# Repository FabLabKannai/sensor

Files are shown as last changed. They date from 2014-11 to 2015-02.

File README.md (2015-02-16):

FabLab Kannai Sensor Project
======

### Arduino Sensor Shield.
This shield have sensors below .<br>
- Temperature and humidity : DHT11<br>
- Air Pressure : MPL115A2<br>
- Light : NJL7502L<br>
- Noise : Condenser Microphone C9267<br>

Separately, requires the Arduino UNO and WiFi shield .<br>

## Sample code
Two types of Arduino sketch 
- Display the measured values on the PC with USB serial.
- Send the measured values to the server with WiFi shield.

Server side program
- Receive the measured values, and display on WEB site.

## Directries
arduino : Arduino sketch <br>
server : Server side program, PHP <br>
eagle : Board data, Eagle format <br>
case : Case data, Adobe illustrator format <br>
docs : Photos and documents <br>

## License
Souce code : Apache License 2.0<br>
Othes :  Creative Commons BY-SA

## Blog (in Japanese)
Sensor Project<br>
http://fablab-kannai.org/sensor_project <br>
Arduino Sensor Shield<br>
http://fablab-kannai.org/archives/787 <br>

## Photo
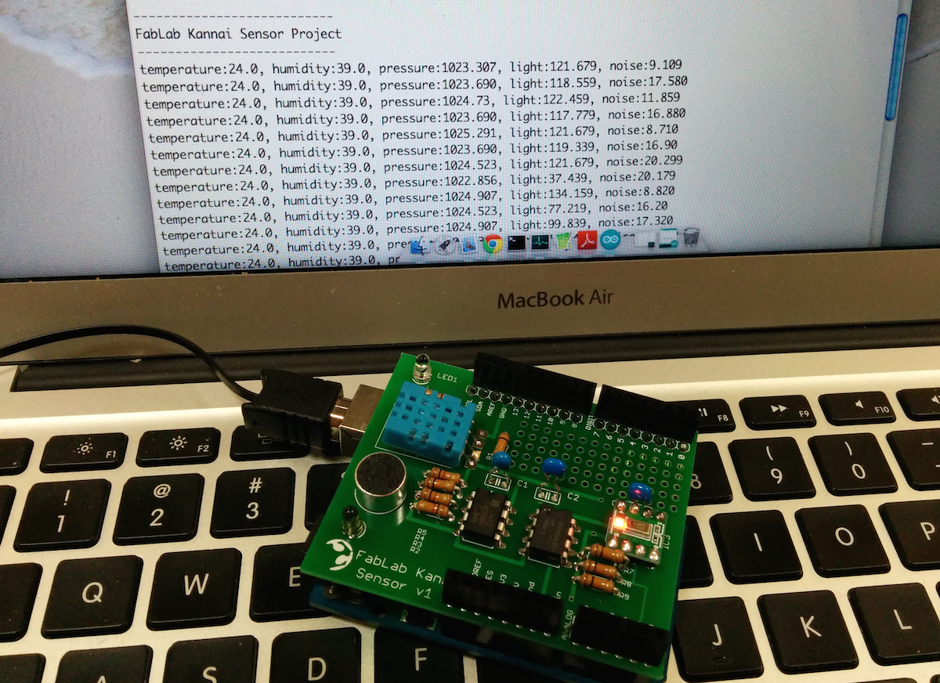
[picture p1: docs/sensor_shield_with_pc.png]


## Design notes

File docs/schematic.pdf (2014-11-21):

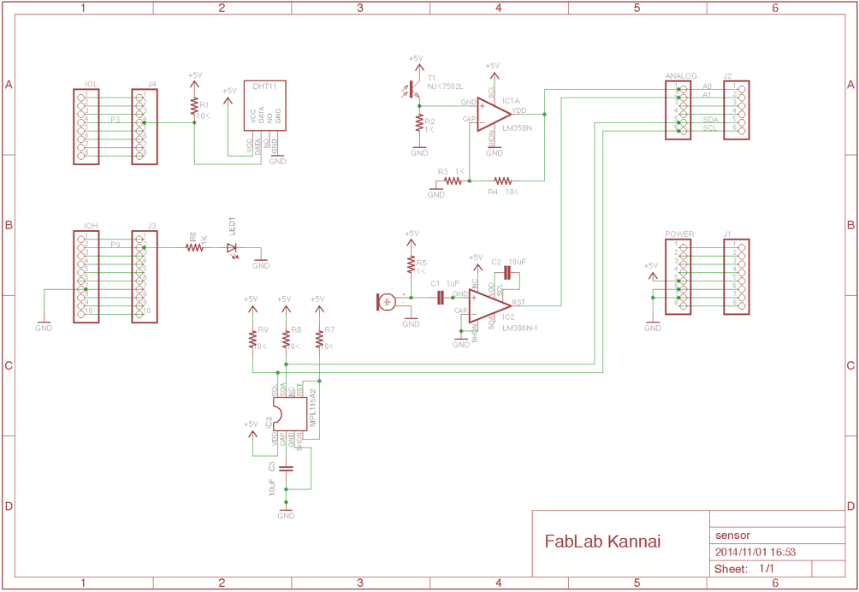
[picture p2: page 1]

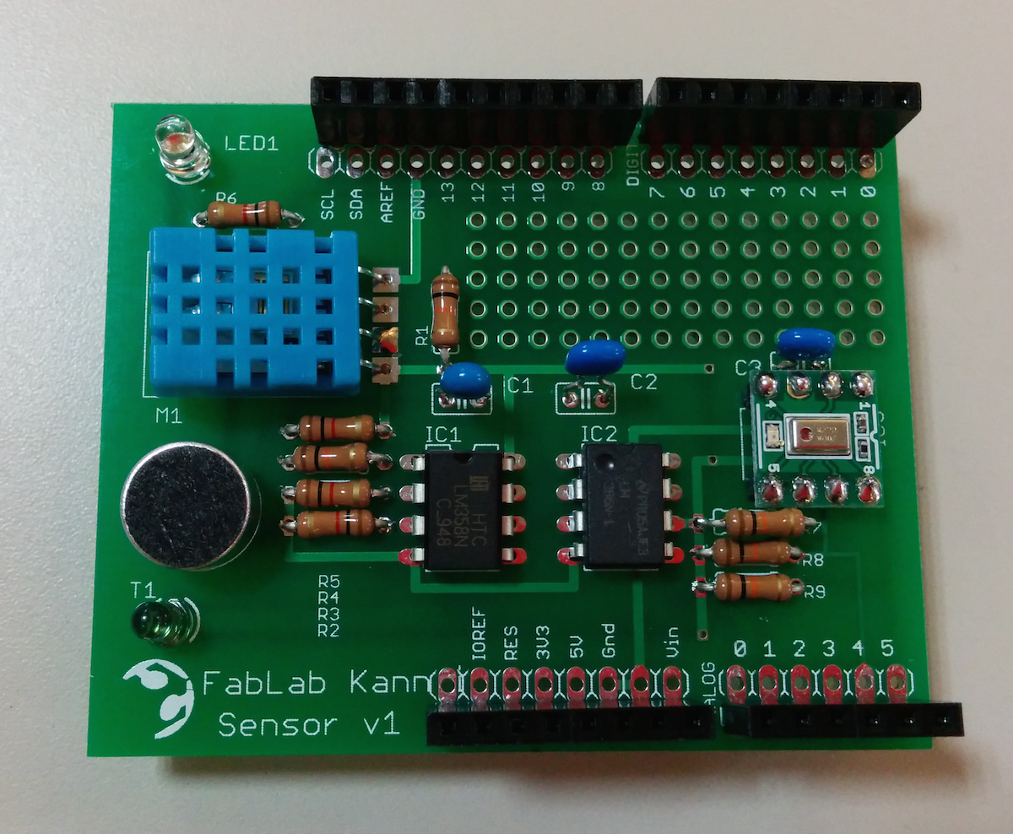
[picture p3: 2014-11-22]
docs/board_front.png

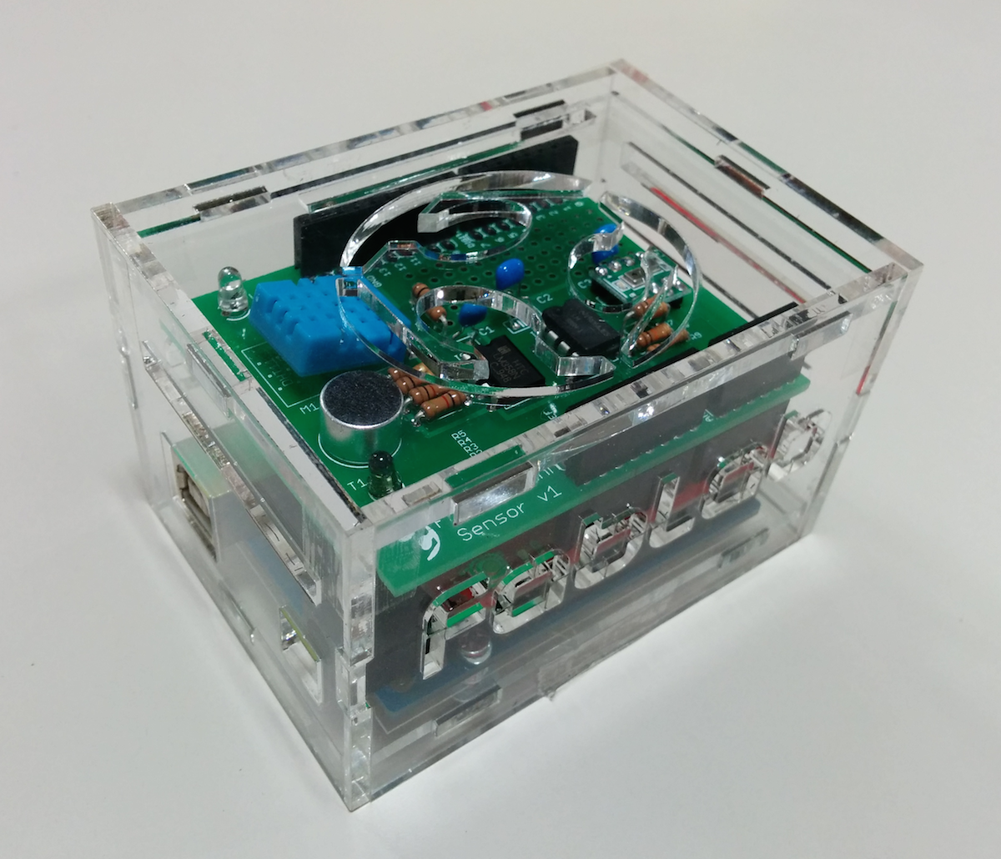
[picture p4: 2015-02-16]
docs/sensor_case.png

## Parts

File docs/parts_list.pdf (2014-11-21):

### Fab-Sensor 部品リスト

種類 | シンボル名 | 品名 | 購入先
基板 | --- | --- | ---
オペアンプ | IC1 | LM358N | http://akizukidenshi.com/catalog/g/gI-02324/
オーディオアンプ | IC2 | LM386N-1 | http://akizukidenshi.com/catalog/g/gI-02250/
気圧センサ | IC3 | MPL115A2 | http://akizukidenshi.com/catalog/g/gI-06521/
温度・湿度センサ | U1 | DHT11 | http://akizukidenshi.com/catalog/g/gM-07003/
光センサ | T1 | NJL7502L | http://akizukidenshi.com/catalog/g/gI-02325/
マイク | M1 | C9267 | http://akizukidenshi.com/catalog/g/gP-01810/
LED | LED1 | LED3MM | http://akizukidenshi.com/catalog/g/gI-00562/
抵抗 | R1,R4,R7,R8,R9 | 10KΩ | http://akizukidenshi.com/catalog/g/gR-25103/
| R2,R3,R5,R6 | 1KΩ | http://akizukidenshi.com/catalog/g/gR-25102/
コンデンサー | C1 | 1uF | http://akizukidenshi.com/catalog/g/gP-03093/
| C2,C3 | 10uF | http://akizukidenshi.com/catalog/g/gP-03095/
ピンヘッダー | IOH | 1x10 | http://akizukidenshi.com/catalog/g/gC-07199/
| POWER, IOH | 1x8 | http://akizukidenshi.com/catalog/g/gC-04046/
| ANALOG | 1X6 | http://akizukidenshi.com/catalog/g/gC-04045/

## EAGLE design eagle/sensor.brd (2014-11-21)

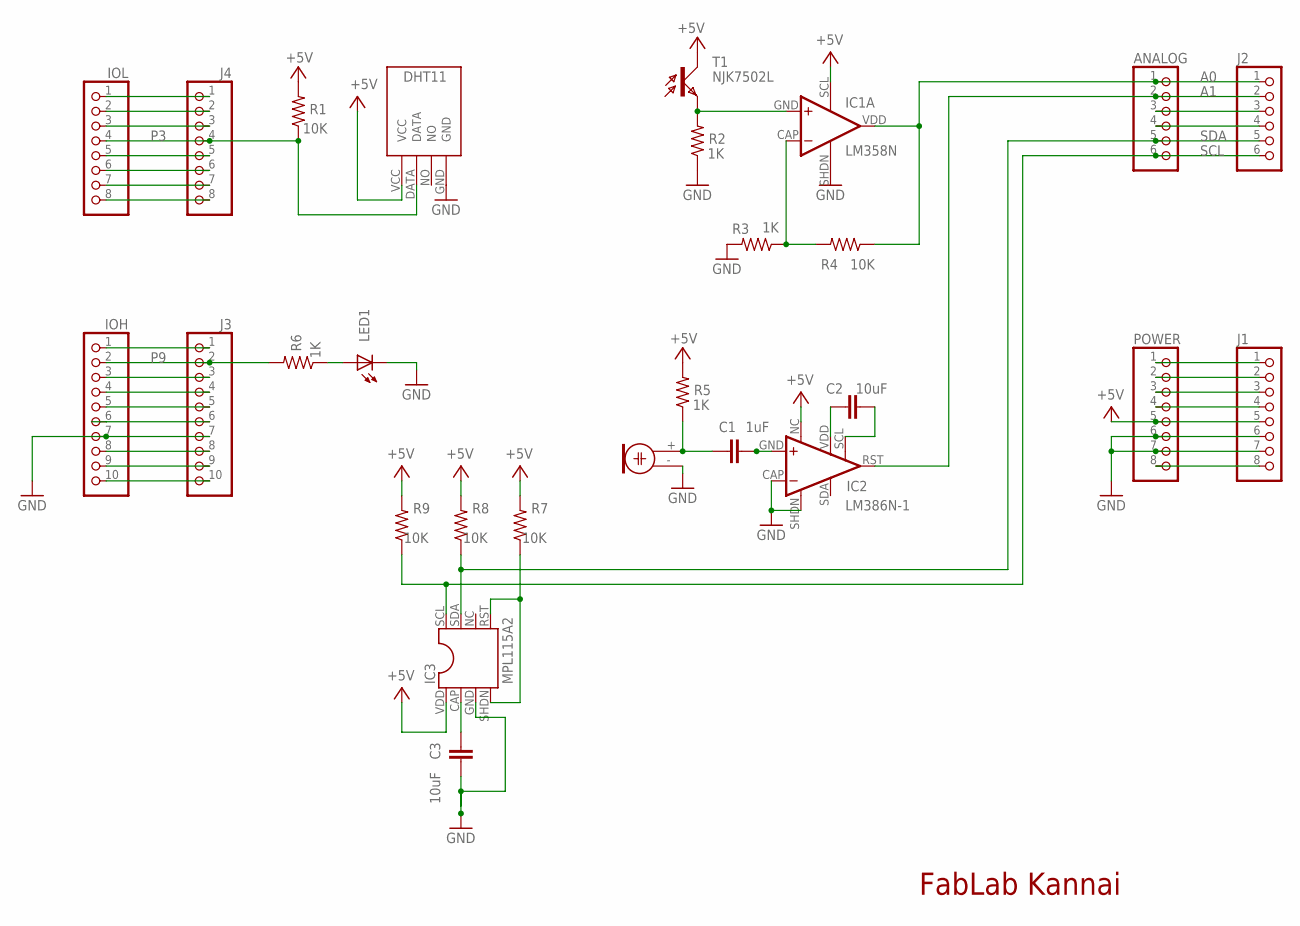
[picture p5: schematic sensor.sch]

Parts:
ANALOG: PINHD-1X6; 1X06
C1: 1uF; C025-025X050
C2, C3: 10uF; C025-025X050
IC1: LM358N; MPL115A2-DIL08
IC2: LM386N-1; MPL115A2-DIL08
IC3: MPL115A2; MPL115A2-DIL08
IOH: PINHD-1X10TH; 1X10-TH
IOL: PINHD-1X8TH; 1X08-TH
J1, J4: PINHD-1X8TH; 1X08-TH
J2: PINHD-1X6; 1X06
J3: PINHD-1X10TH; 1X10-TH
LED1: LED3MM
M1: C9257; DB-C9767
POWER: PINHD-1X8TH; 1X08-TH
R1, R4, R7, R8, R9: 10K; 0204/7
R2, R3, R5, R6: 1K; 0204/7
T1: NJK7502L; NJL7502L
U$1: DHT11

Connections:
+9V: J1.8, POWER.8
A0: ANALOG.1, IC1.VDD (OUT), J2.1, R4.1
A1: ANALOG.2, IC2.RST (OUT), J2.2
A2: ANALOG.3, J2.3
A3: ANALOG.4, J2.4
AREF: IOH.8, J3.8
GND: C3.2, IC1.SHDN (V-), IC2.CAP (-IN), IC2.SHDN (GND), IC3.GND, IOH.7, J1.6, J1.7, J3.7, LED1.K (C), M1.- (2), POWER.6, POWER.7, R2.1, R3.2, U$1.GND
unnamed: IOH.9, J3.9
unnamed: IOH.10, J3.10
unnamed: IC1.SCL (V+), IC2.NC (VS), IC3.VDD, J1.5, POWER.5, R1.2, R5.2, R7.2, R8.2, R9.2, T1.C, U$1.VCC
unnamed: IC1.GND (+IN), R2.2, T1.E
unnamed: IC3.RST, IC3.SHDN, R7.1
unnamed: IC1.CAP (-IN), R3.1, R4.2
unnamed: C3.1, IC3.CAP
unnamed: C2.1, IC2.VDD (GAIN)
unnamed: J1.2, POWER.2
unnamed: J1.1, POWER.1
unnamed: C1.2, IC2.GND (+IN)
unnamed: C2.2, IC2.SCL (GAIN)
unnamed: C1.1, M1.+ (1), R5.1
unnamed: LED1.A, R6.1
unnamed: J1.4, POWER.4
P0: IOL.1, J4.1
P1: IOL.2, J4.2
P2: IOL.3, J4.3
P3: IOL.4, J4.4, R1.1, U$1.DATA
P4: IOL.5, J4.5
P5: IOL.6, J4.6
P6: IOL.7, J4.7
P7: IOL.8, J4.8
P8: IOH.1, J3.1
P9: IOH.2, J3.2, R6.2
P10: IOH.3, J3.3
P11: IOH.4, J3.4
P12: IOH.5, J3.5
P13: IOH.6, J3.6
RESET: J1.3, POWER.3
SCL: ANALOG.6, IC3.SCL, J2.6, R9.1
SDA: ANALOG.5, IC3.SDA, J2.5, R8.1

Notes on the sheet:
FabLab Kannai

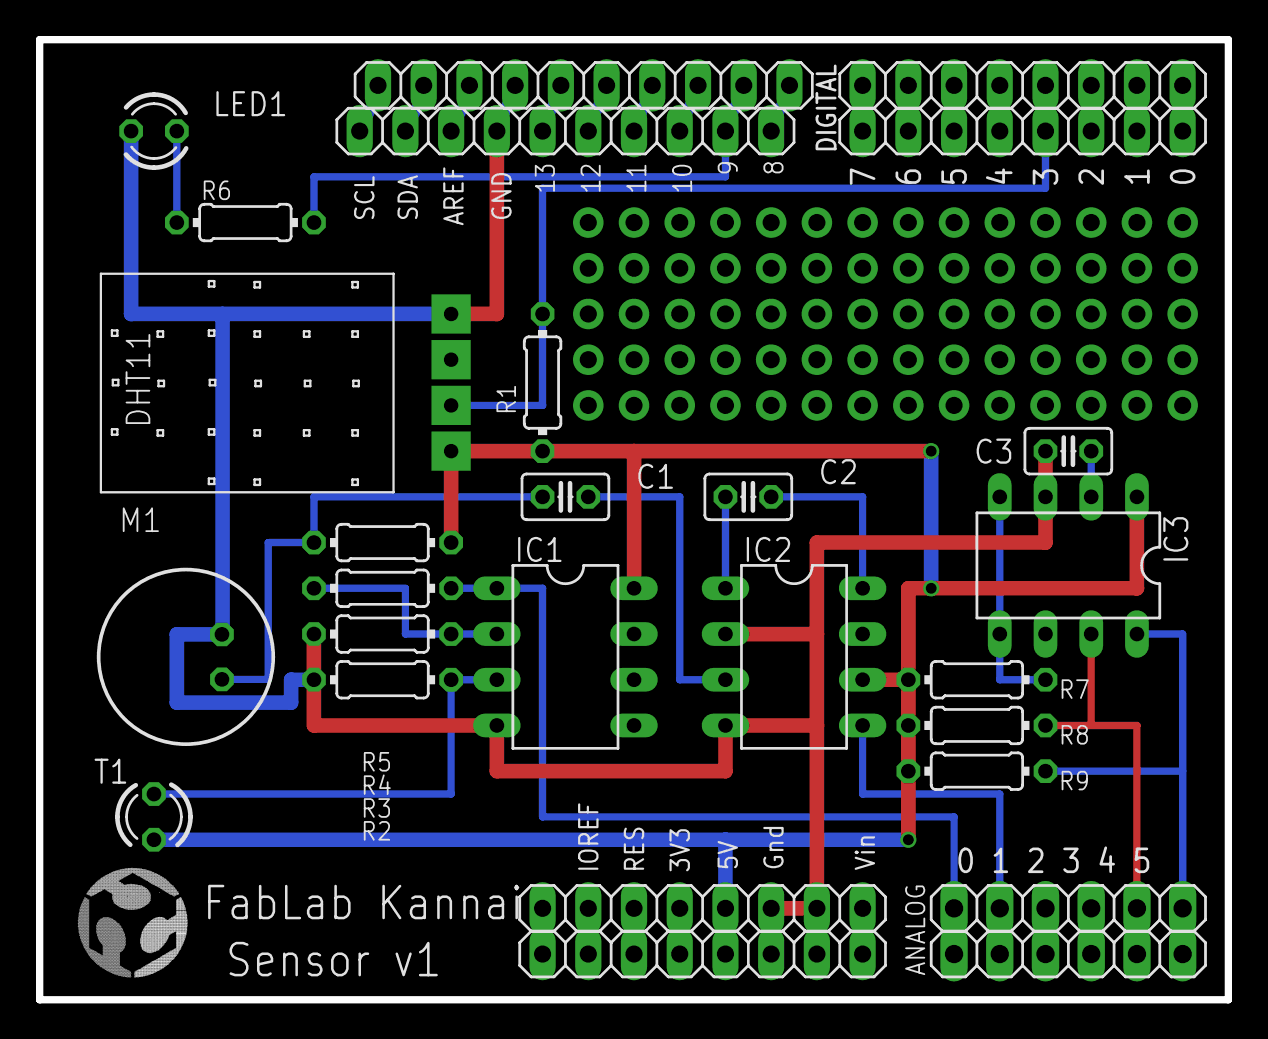
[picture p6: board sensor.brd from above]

Board: 2 copper layers, 66.0 x 53.3 mm, 27 parts (0 on the bottom side), 39 nets.

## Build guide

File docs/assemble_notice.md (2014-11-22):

ハンダ付けする際の注意
==========================

(1) LEDと光センサは、外観の形状は同じなので、色で識別してください。LEDは無色 (発光色は青) で、光センサは深緑色です。基板のシルクからは極性が判断できません。下図を参考にしてください。<br>
(2) 気圧センサと抵抗の間に物理的な余裕がありません。抵抗をハンダ付けしたあとで、気圧センサをハンダ付けしてください。<br>
(3) コンデンサのピンの幅は２ピッチですが、基板は１ピッチです。ピンを伸ばすなどして、取り付けてください。<br>

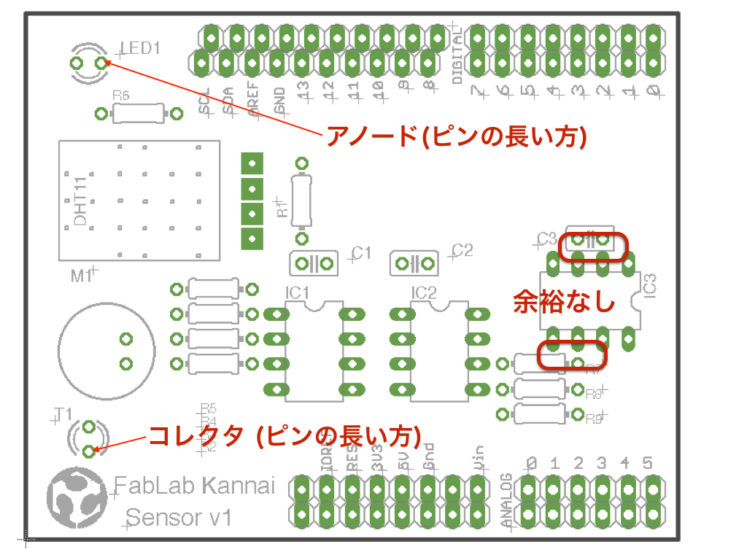
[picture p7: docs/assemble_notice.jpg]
notice


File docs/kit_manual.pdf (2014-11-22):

# FabLab Kannai センサー・シールド

# Arduino 用のシールドです。

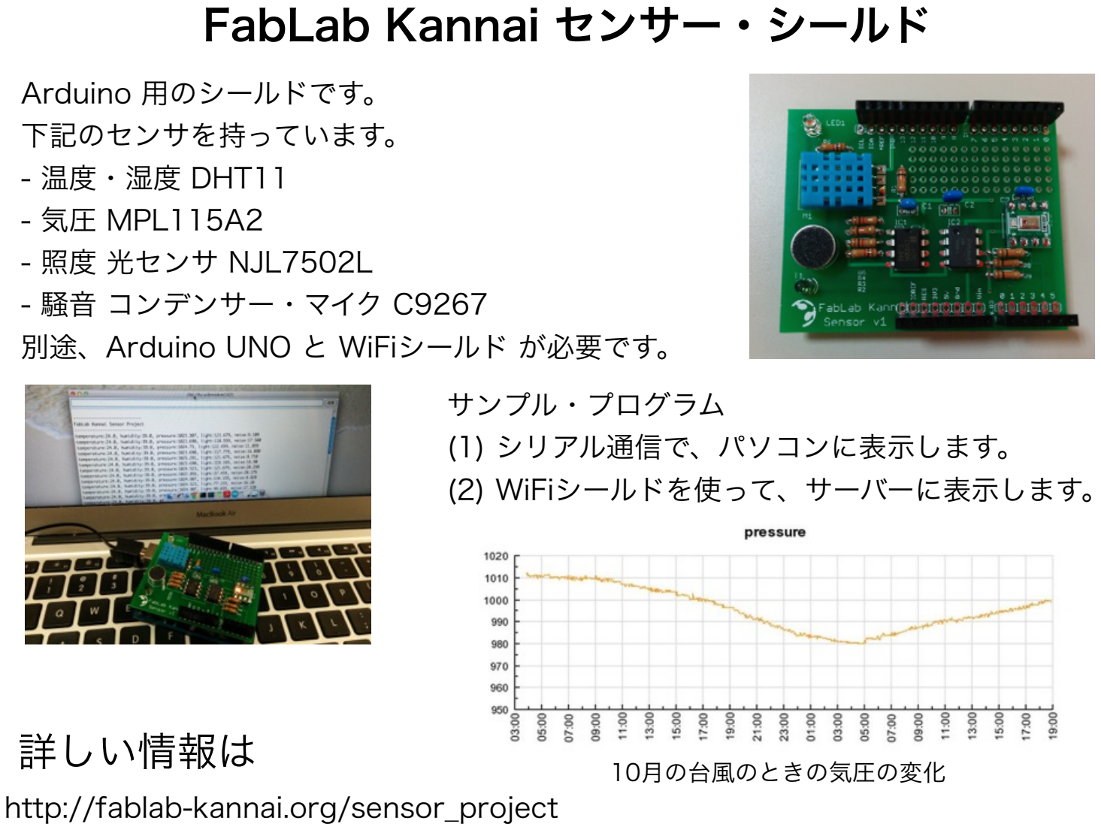
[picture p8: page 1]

# 下記のセンサを持っています。 - 温度・湿度 DHT11 - 気圧 MPL115A2 - 照度 光センサ NJL7502L - 騒音 コンデンサー・マイク C9267 別途、Arduino UNO と WiFiシールド が必要です。

# サンプル・プログラム (1) シリアル通信で、パソコンに表示します。 (2) WiFiシールドを使って、サーバーに表示します。

# 10月の台風のときの気圧の変化

# http://fablab-kannai.org/sensor_project

# 詳しい情報は

# FabLab Kannai センサー・シールド

種類 | シンボル名 | 品名
基板 | --- | ---
オペアンプ | IC1 | LM358N
オーディオアンプ | IC2 | LM386N-1
気圧センサ | IC3 | MPL115A2
温度・湿度センサ | U1 | DHT11
照度センサ | T1 | NJL7502L
マイク | M1 | C9267
LED | LED1 | LED3MM
抵抗 | R1,R4,R7,R8,R9 | 10KΩ

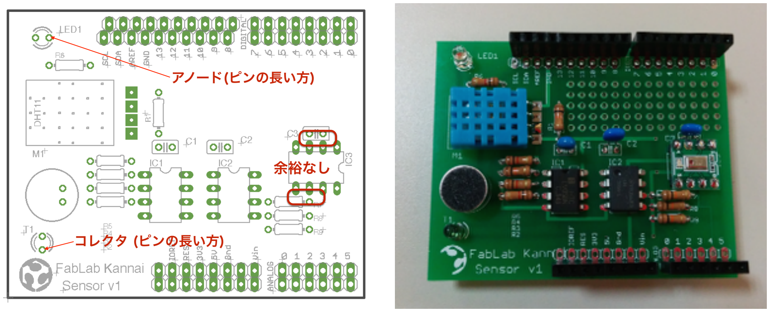
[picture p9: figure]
アノード(ピンの長い方); コレクタ (ピンの長い方); 余裕なし

R2,R3,R5,R6 | 1KΩ
コンデンサー | C1 | 1uF
| C2,C3 | 10uF
ピンヘッダー | IOH | 1x10
| POWER, IOH | 1x8
| ANALOG | 1X6

# (1) LEDと光センサは、外観の形状は同じなので、色で識別 してください。LEDは無色 (発光色は青) で、光センサは深 緑色です。 基板のシルクからは極性が判断できません。下 図を参考にしてください。 (2) 気圧センサと抵抗の間に物理的な余裕がありません。 抵抗をハンダ付けしたあとで、気圧センサをハンダ付けして ください。 (3) コンデンサのピンの幅は２ピッチですが、基板は１ピッ チです。ピンを伸ばすなどして、取り付けてください。

部品リスト | ハンダ付けする際の注意

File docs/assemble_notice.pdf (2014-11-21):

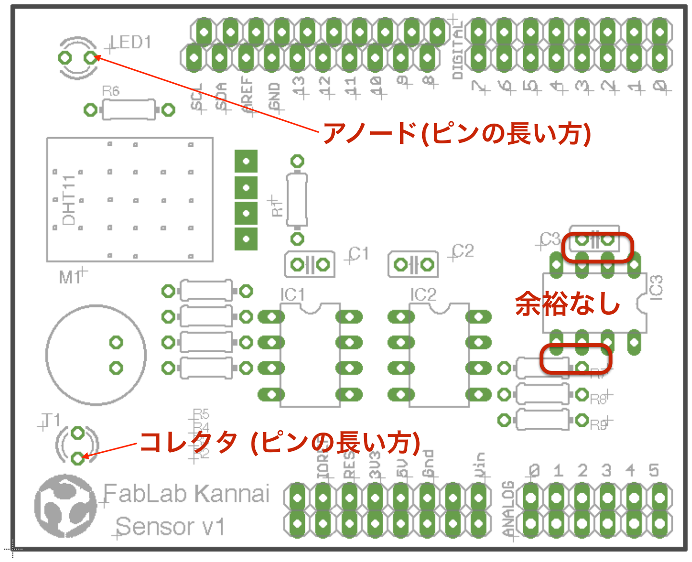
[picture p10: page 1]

アノード(ピンの長い方)

コレクタ (ピンの長い方)

余裕なし

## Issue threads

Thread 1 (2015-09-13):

Light Sensor Coefficient

stelgenhof, 2015-09-13:
Hi,

Thank you very much for this sensor project. I am building this myself and am wondering what the coefficient number in the sensor code (0.78) is representing.

It looks like it is used for converting the analogue pin out to a Lux value. Is that correct. I am using the same light photo diode (NJ7502) and was wondering how you determined that number 0.78. I have made a formula for converting to Lux, but am not convinced the output is correct.

Closed 2023-12-04.

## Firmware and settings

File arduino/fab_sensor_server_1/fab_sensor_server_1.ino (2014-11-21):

/**
 * Sensor for Server with Wifi
 * Temperature, Humidity, Light, Noise,  Air Pressure
 * 
 * FabLab Kannai Sensor Project
 * 2014-08-20
 */ 

/*
 * require
 * SFE_CC3000_Library 
 *   https://github.com/sparkfun/SFE_CC3000_Library
 *   and modify SFE_CC3000.cpp
 * Arduino Library for the DHT11
 *   https://github.com/adafruit/DHT-sensor-library
 * Driver for the Adafruit MPL115A2 barometric pressure sensor breakout
 *   https://github.com/adafruit/Adafruit_MPL115A2
 */

/**
 * send data
 * { "temperature":11.1, "humidity":22.2, "light":33.3, "noise":44.4, "pressure":55.5 }
 *
 * response
 * { "code": 1 }
 */

/**
 * Sensor Device
 * Temperature & Humidity : DHT11
 * Air Pressure : MPL115A2
 * Light : NJL7502L
 * Noise : Microphone C9767BB422LFP
 */

// WiFi 
#include <SPI.h>
#include <SFE_CC3000.h>
#include <SFE_CC3000_Client.h>

// Air Pressure
#include <Wire.h>
#include <Adafruit_MPL115A2.h>

// Temperature & Humidity
#include <DHT.h>

#include <avr/wdt.h>
#include "config.h"

// Pins
#define CC3000_INT  2  // Needs to be an interrupt pin (D2/D3)
#define CC3000_EN  7  // Can be any digital pin
#define CC3000_CS  10  // Preferred is pin 10 on Uno
#define PIN_DHT  3
#define PIN_LED  9
#define PIN_LIGHT  A0
#define PIN_NOISE  A1

// param
#define PARAM_TEMP   "param={\"temperature\":"
#define PARAM_HUMI   ",\"humidity\":"
#define PARAM_LIGHT  ",\"light\":"
#define PARAM_NOISE  ",\"noise\":"
#define PARAM_PRESS  ",\"pressure\":"
#define PARAM_END    "}"

// Sensor   
#define DHTTYPE  DHT11   // DHT 11 
#define UNDIFINED_VALUE  -1
#define NOISE_OFFSET 512
#define AVARAGE_NUM  100
#define DECIMAL_DIGIT  1000

// --- todo ---
#define COFF_LIGHT  0.78

// Serial
#define SERIAL_SPEED  9600

// Access Point
#define IP_ADDR_LEN  4  // Length of IP address in bytes
#define AP_TIMEOUT  30000  // 30 sec
#define AP_SECURITY  WLAN_SEC_WPA2  // Security of network

// Server
#define SERVER_PORT  80
#define SERVER_PATH_BEGIN  "/~"

// Response
#define TIME_RESPONSE  1  // 1 msec
#define RESPONSE_TIMEOUT  5000  // 5 sec

// loop
#define MAX_NOT_SEND  10
#define TIME_LOOP  1000  // 1 sec

// CC3000
SFE_CC3000 wifi = SFE_CC3000( CC3000_INT, CC3000_EN, CC3000_CS );
SFE_CC3000_Client client = SFE_CC3000_Client( wifi );

// DHT
DHT dht( PIN_DHT, DHTTYPE );

// MPL115A2
Adafruit_MPL115A2 mpl115a2;

// Server IP Address
IPAddress host_addr;

// length of param characters
int param_len = 0;

// led
boolean led_status = false;

// counter that cannot send wifi 
unsigned int cnt_not_send = 0;

// time which excute to send data
unsigned long time_excute = 0;

boolean is_connected = false;

// proc wdt_reset if 1
boolean is_wdt = true;

/**
 * === setup ===
 */ 
void setup() {
	// Initialize Serial port
	Serial.begin( SERIAL_SPEED );
	Serial.println();
	Serial.println( F("---------------------------") );
	Serial.println( F("FabLab Kannai Sensor Project") );
	Serial.println( F("---------------------------") );
	// setting
	pinMode( PIN_LED, OUTPUT );	
	dht.begin();
	mpl115a2.begin();	
	setup_wifi();
	setup_param_len();
	wdt_enable( WDTO_8S );
}

/**
 * setup_wifi
 */
void setup_wifi() {  
	// Initialize CC3000 (configure SPI communications)
	if ( wifi.init() ) {
		Serial.println( F("CC3000 initialization complete") );
	} else {
		Serial.println( F("Something went wrong during CC3000 init!") );
	} 
}

/**
 * setup_param_len
 */
void setup_param_len() {  
	param_len = 0;
	String str = PARAM_TEMP;
	param_len += str.length();
	str = PARAM_HUMI ; 
	param_len += str.length();
	str =  PARAM_LIGHT ;  
	param_len += str.length();
	str = PARAM_NOISE ;
	param_len += str.length();
	str = PARAM_PRESS ;
	param_len += str.length();
	str = PARAM_END ;
	param_len += str.length();
}
	
/**
 * === loop ===
 */ 
void loop() {
	// every 60 sec
	if ( (millis() - time_excute) > TIME_UPLOAD ) {
		time_excute = millis();
		exec_wifi();
	}
	// if wdt enabled
	if ( is_wdt ) {
		wdt_reset();
		// blink LED
		led_status = !led_status;
		if ( led_status ) {
			digitalWrite( PIN_LED, HIGH );
		} else {
  			digitalWrite( PIN_LED, LOW );
		}
	}
	// wait 1 sec
	delay( TIME_LOOP ); 
}

/**
 * exec_wifi
 */
void exec_wifi() {
	is_wdt = true;
	boolean is_ok = false;
	if ( is_connected && wifi.getConnectionStatus() ) {
		if ( send_recv_wifi() ) {
			is_ok = true;
			cnt_not_send = 0;
		}
	} else {
		is_connected = connect_wifi(); 
	}
	if ( !is_ok ) {
		cnt_not_send ++;
	}
	if ( cnt_not_send  > MAX_NOT_SEND ) {
		is_wdt = false;
	}
}

/**
 * connect_wifi
 */
boolean connect_wifi() {
	ConnectionInfo connection_info;
	int i;

	// Connect using DHCP
	Serial.println();
	Serial.print( F("Connecting to SSID: ") );
	Serial.println( F(AP_SSID) );
	if( !wifi.connect( AP_SSID, AP_SECURITY, AP_PASS, AP_TIMEOUT )) {
		Serial.print( F("Error: Could not connect to AP : ") );
		Serial.println( cnt_not_send );
		return false;
	}

	// Gather connection details and print IP address
	if ( !wifi.getConnectionInfo( connection_info ) ) {
		Serial.println( F("Error: Could not obtain connection details") );
		return false;
	}	
	
	Serial.print( F("AP IP Address: ") );
	for (i = 0; i < IP_ADDR_LEN; i++) {
		Serial.print( connection_info.ip_address[ i ] );
		if ( i < IP_ADDR_LEN - 1 ) {
			Serial.print( F(".") );
		}
	}
	Serial.println();

	/* Perform a DNS lookup of the site */
    if ( !wifi.dnsLookup( SERVER_HOST, &host_addr )) {
		Serial.println( F("Error: Could not DNS Lookup") );
        return false;
    }

	Serial.print( F("HOST IP Address: ") );
	for (i = 0; i < IP_ADDR_LEN; i++) {
		Serial.print( host_addr[ i ] );
		if ( i < IP_ADDR_LEN - 1 ) {
			Serial.print( F(".") );
		}
	}
	Serial.println();

	return true;
}

/**
 * send wifi 
 */
boolean send_recv_wifi() {
// --- read sensor ---
	wdt_reset();
	// DHT
    float temp = dht.readTemperature();
  	float humi = dht.readHumidity();
	// Check if any reads failed
  	if ( isnan(temp) || isnan(humi) ) {
    	temp = UNDIFINED_VALUE;
		humi = UNDIFINED_VALUE;
		Serial.println( F("Failed to read from DHT sensor!") );
  	}

  	// light
    int light_raw = analogRead( PIN_LIGHT );
    float light = COFF_LIGHT * (float)light_raw;
  	// noise
    float noise_raw = read_analog_average( PIN_NOISE );
    float noise = abs( noise_raw - NOISE_OFFSET );
  	// air pressure
    float pressure = 10 * mpl115a2.getPressure();

	String str_temp = conv_string( temp );
	String str_humi = conv_string( humi );
	String str_light = conv_string( light );
	String str_noise = conv_string( noise );
	String str_press = conv_string( pressure );
	
	int len = param_len;
	len += str_temp.length();
	len += str_humi.length();
	len += str_light.length();
	len += str_noise.length();
	len += str_press.length();

// --- connection ---
	wdt_reset();
	Serial.println();
	Serial.print( F("Connect to ") );
	Serial.println( F(SERVER_HOST) );
	if ( !client.connect( host_addr, SERVER_PORT ) ) {
		Serial.print( F("Error: Could not make a TCP connection : ") );
		Serial.println( cnt_not_send );
		return false;
	}

// --- print ---
	wdt_reset();					
	//	server path
	Serial.print( F(SERVER_PATH) );
	Serial.println();
	//	body
	Serial.print( F(PARAM_TEMP) );
	Serial.print( str_temp );
	Serial.print( F(PARAM_HUMI) );
	Serial.print( str_humi );
	Serial.print( F(PARAM_LIGHT) );
	Serial.print( str_light );
	Serial.print( F(PARAM_NOISE) );
	Serial.print( str_noise );
	Serial.print( F(PARAM_PRESS) );
	Serial.print( str_press );
	Serial.print( F(PARAM_END) );
	Serial.println();

// --- send ---
	wdt_reset();
	// send POST method            
	client.print( F("POST ") );
	//	server path
	client.print( F(SERVER_PATH) );
	client.println( F(" HTTP/1.1") );
	// Host  
	client.print( F("Host: ") );
	client.println( F(SERVER_HOST) );
	// Connection 
	client.println( F("Connection: close") );
	// Content-Length 
	client.print( F("Content-Length: ") );
	client.println( len );
	// Content-Type 
	client.println( F("Content-Type: application/x-www-form-urlencoded") );
	// end of header
	client.println();
	// body
	client.print( F(PARAM_TEMP) );
	client.print( str_temp );
	client.print( F(PARAM_HUMI) );
	client.print( str_humi );
	client.print( F(PARAM_LIGHT) );
	client.print( str_light );
	client.print( F(PARAM_NOISE) );
	client.print( str_noise );
	client.print( F(PARAM_PRESS) );
	client.print( str_press );
	client.print( F(PARAM_END) );
	client.println();

// --- recieve --
	wdt_reset();
	boolean ret = recv_wifi();
	Serial.println();
	if ( ret ) {
		Serial.println( F("code OK") );
	} else {
		Serial.println( F("code NG") );
	}

// --- close ---
	wdt_reset();
	Serial.println();
	if ( !client.close() ) {
		Serial.println( F("Error: Could not close client") );
		return false;
	}
	Serial.println( F("Closed client") ); 
	return ret;
}

/**
 * read_analog_average
 */
float read_analog_average( int pin ) {
	long total = 0;
	for( int i=0; i < AVARAGE_NUM; i++ ) {
		total += analogRead( pin );
	}
	float average = (float)total / AVARAGE_NUM;  
	return average;
}
	
/**
 * recv_wifi
 */
boolean recv_wifi() {
	boolean is_body = false;
	boolean is_ok = false;
	char data = 0;
	char c[7] = {0, 0, 0, 0, 0, 0, 0};
    unsigned long time = millis();
	while ( client.connected() ) {
		if ( client.available() ) {
			data = client.read();
			Serial.print( data );
			c[0] = c[1];
			c[1] = c[2];
			c[2] = c[3];
			c[3] = c[4];
			c[4] = c[5];			
			c[5] = c[6];	
			c[6] = data;	
			// boundary of header and body
			if (( c[0] == 0x0D )&&( c[1] == 0x0A )&&( c[2] == 0x0D )&&( c[3] == 0x0A )) {
  is_body = true;
			}
			// "code: 1"
			if ( is_body &&( c[0] == 'c' )&&( c[1] == 'o' )&&( c[2] == 'd' )&&( c[3] == 'e' )&&( c[4] == ':' )&&( c[5] == ' ' )&&( c[6] == '1' )) {
				is_ok = true;
			}
		}
		// If 5 sec pass, go out the loop of response
		delay( TIME_RESPONSE );
		if ( (millis() - time) > RESPONSE_TIMEOUT ) {
			return false;
		}
		wdt_reset();
	}
	Serial.println();
	return is_ok;
}

/**
 * conv_string
 */
String conv_string( float value ) { 
	int sign = 1;
	if ( value < 0 ) {
		value = -value;
		sign = -1;
	}
 	int integer = (int)value;
 	int deci = (int)( 1000 * ( value - (float)integer ) );
	String str = String( sign * integer );
	str.concat( "." );
	str.concat( deci );
	return str;
}
